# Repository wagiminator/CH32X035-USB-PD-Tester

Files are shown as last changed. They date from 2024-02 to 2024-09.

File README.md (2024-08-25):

# USB PD Tester
The USB PD Tester is a monitoring and triggering device designed for USB Power Delivery. It allows you to test a wide range of USB Type-C PD power supplies and their corresponding cables. This tool not only displays the capabilities of the power supply on an OLED but also enables you to select one of the available fixed or programmable voltages for output on the screw terminal. With this, it can also be used to power your projects with various selectable voltages and high currents, serving as a versatile variable power supply.

The USB PD Tester is built around the inexpensive (30 cents at the time of writing) and user-friendly CH32X035 RISC-V microcontroller, which comes with integrated USB 2.0, USB PD 2.0/3.0, and USB Type-C hardware support.

- Project video (Youtube): https://youtu.be/wqLiRnbcISo

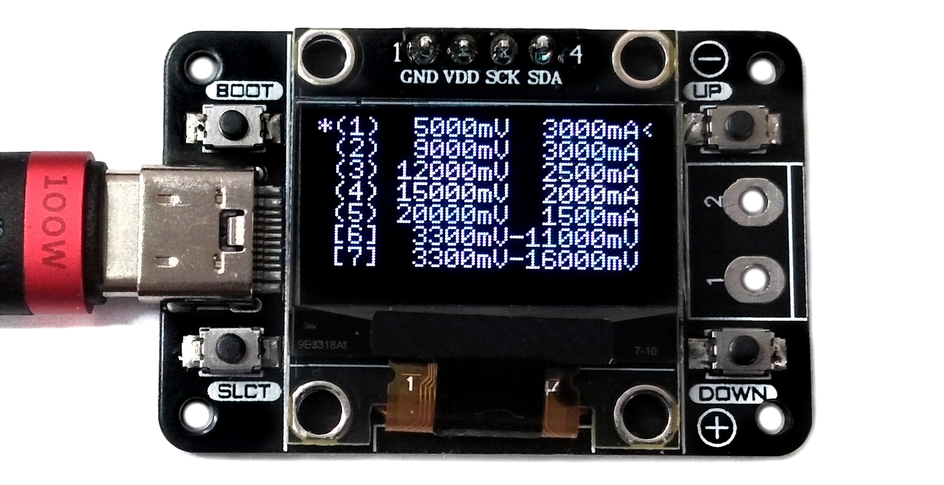
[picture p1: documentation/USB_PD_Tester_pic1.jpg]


# USB Power Delivery
USB Power Delivery (USB PD) is a protocol that extends the capabilities of standard USB connections, allowing for faster charging and power delivery between devices. USB PD operates through negotiation between the source and sink devices. They exchange information through PDOs, determining the optimal power level for charging or powering the sink device. PPS enhances flexibility by allowing dynamic adjustments, and CC1 and CC2 are the communication channels involved in the negotiation process:
- Source: The source is a device that provides power, such as a charger or power bank. It can negotiate with the connected device to determine the optimal power level. Here the USB PD power supply to be tested acts as the source.
- Sink: The sink is a device that consumes power, like a smartphone or laptop. It communicates with the source to negotiate the power it needs for charging or other operations. Here the USB PD Tester acts as the sink.
- PDO (Power Delivery Object): A PDO is a data structure exchanged between the source and sink during negotiation. It contains information about the available voltage and current levels. The devices negotiate and agree on a mutually supported PDO for power delivery.
- PPS (Programmable Power Supply): PPS is a feature in USB PD that allows dynamic adjustment of the voltage and current levels during operation. It enables more flexible power delivery based on the specific needs of the connected device.
- CC1 and CC2 (Configuration Channel 1 and 2): These are the communication channels used by USB Type-C connectors for negotiating power delivery. CC1 and CC2 lines carry information about the capabilities of the devices and facilitate negotiation.

# Hardware
## Schematic
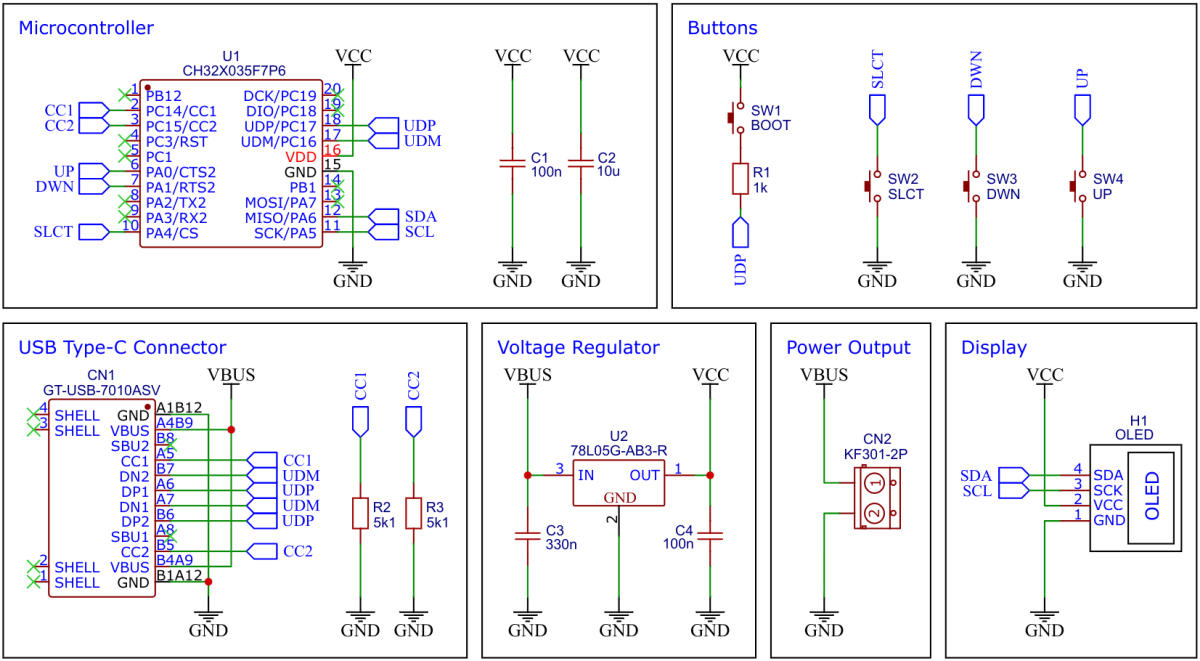
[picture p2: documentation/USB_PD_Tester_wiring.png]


## CH32X035 F7P6 32-bit RISC-V USB Microcontroller
CH32X035F7P6 is a low-cost microcontroller that utilizes the QingKe 32-bit RISC-V4C core, supporting the RV32IMAC instruction set along with self-extending instructions. This microcontroller comes with a built-in USB PHY, supporting USB2.0 full-speed device functions and a USB PD PHY with source and sink capabilities. It features a programmable protocol I/O controller (PIOC), an operational amplifier (OPA) with programmable gain (PGA), an analog comparator (CMP), a 12-bit analog-to-digital converter (ADC), an 11-channel touch-key controller, 3 groups of USART, I2C, SPI, multiple timers, and various other peripheral resources. The device can operate at clock frequencies of up to 48MHz and is compatible with a supply voltage range of 2.0V to 5.5V. The CH32X035F7P6 includes 48KB of flash, 20KB of SRAM, and an embedded USB bootloader.

## 78L05 Voltage Regulator
The 78L05 is a simple and inexpensive voltage regulator that can convert input voltages up to 30V to an output voltage of 5V with an output current of up to 100mA and a dropout voltage of 1.7V. The 78L05 supplies all elements of the circuit with up to 5V.

## SSD1306 OLED Display Module
A low-cost SSD1306 4-pin I2C 128x64 pixels 0.96-inch OLED module is used as the display device. Make sure to acquire one with the correct pinout!

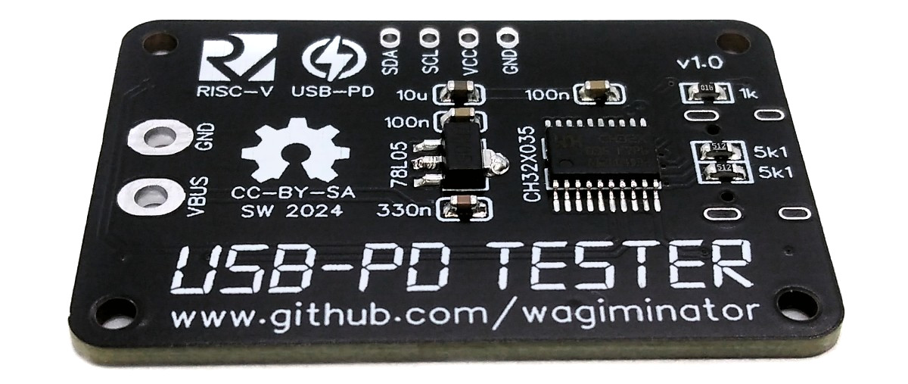
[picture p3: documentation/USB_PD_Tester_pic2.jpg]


# Software
## USB Bootloader
### Installing Drivers for the Bootloader
On Linux you do not need to install a driver. However, by default Linux will not expose enough permission to upload your code with the USB bootloader. In order to fix this, open a terminal and run the following commands:

```
echo 'SUBSYSTEM=="usb", ATTR{idVendor}=="4348", ATTR{idProduct}=="55e0", MODE="666"' | sudo tee /etc/udev/rules.d/99-ch55x.rules
echo 'SUBSYSTEM=="usb", ATTR{idVendor}=="1a86", ATTR{idProduct}=="55e0", MODE="666"' | sudo tee -a /etc/udev/rules.d/99-ch55x.rules
sudo udevadm
```

For Windows you can use the [Zadig](https://zadig.akeo.ie/) tool to install the correct driver. Here, click "Options" -> "List All Devices" and select the USB module. Then install the libusb-win32 driver. To do this, the board must be connected and the microcontroller must be in bootloader mode.

### Entering Bootloader Mode
The bootloader must be started manually for new uploads. To do this, the board must first be disconnected from the USB port. Now press the BOOT button and keep it pressed while reconnecting the board to the USB port of your PC. The chip now starts in bootloader mode, the BOOT button can be released and new firmware can be uploaded via USB within the next couple of seconds.

## Compiling and Uploading Firmware using the Makefile
### Linux
Install the toolchain (GCC compiler, Python3, and chprog):
```
sudo apt install build-essential libnewlib-dev gcc-riscv64-unknown-elf
sudo apt install python3 python3-pip
pip install chprog
```

Open a terminal and navigate to the folder with the *makefile*. Press the BOOT button and keep it pressed while connecting the board to the USB port of your PC. Run the following command to compile and upload:
```
make flash
```

### Other Operating Systems
Follow the instructions on [CNLohr's ch32v003fun page](https://github.com/cnlohr/ch32v003fun/wiki/Installation) to set up the toolchain on your respective operating system (for Windows, use WSL). Also, install [Python3](https://www.pythontutorial.net/getting-started/install-python/) and [chprog](https://pypi.org/project/chprog/). Compile and upload with "make flash". Note that I only have Debian-based Linux and have not tested it on other operating systems.

## Compiling and Uploading Firmware using PlatformIO
- Install [PlatformIO](https://platformio.org) and [platform-ch32v](https://github.com/Community-PIO-CH32V/platform-ch32v). Follow [these instructions](https://pio-ch32v.readthedocs.io/en/latest/installation.html) to do so. Linux/Mac users may also need to install [pyenv](https://realpython.com/intro-to-pyenv).
- Click on "Open Project" and select the firmware folder with the *platformio.ini* file.
- Press the BOOT button and keep it pressed while connecting the board to the USB port of your PC. Then click "Upload".

## Uploading pre-compiled Firmware Binary
WCH offers the free but closed-source software [WCHISPTool](https://www.wch.cn/downloads/WCHISPTool_Setup_exe.html) to upload firmware with Windows via the USB bootloader. Press the BOOT button and keep it pressed while connecting the board to the USB port of your PC. Release the BOOT button, open the *pd_tester.hex* file in the *bin* folder with WCHISPTool and upload it to the microcontroller.

If [Python3](https://www.pythontutorial.net/getting-started/install-python/) is installed, you can also use the platform-independent open-source command-line tool [chprog](https://pypi.org/project/chprog/) for uploading:
```
chprog bin/pd_tester.bin
```

# Building Instructions
1. Take the Gerber files (the *zip* file inside the *hardware* folder) and upload them to a PCB (printed circuit board) manufacturer of your choice (e.g., [JLCPCB](https://jlcpcb.com/)). They will use these files to create the circuit board for your device and send it to you.
2. Once you have the PCB, you can start soldering the components onto it. Use the BOM (bill of materials) and schematic as a guide to make sure everything is connected correctly. You can find the corresponding files in the *hardware* folder. Remove the plastic part from the pin header of the OLED, trim the pins, and solder the OLED module flush onto the PCB. Do not solder the screw terminal yet.
3. Print the casing with your 3D printer. You can find the corresponding *stl* files in the *3dprint* folder.
4. Insert the button extensions into the corresponding holes on the top part of the casing. Insert the circuit board and secure it with 4 self-tightening M2x5mm screws.
5. Now solder the screw terminal onto the circuit board.
6. Close the casing with the back panel.
7. Upload the firmware by following the instructions in the previous section (see above).

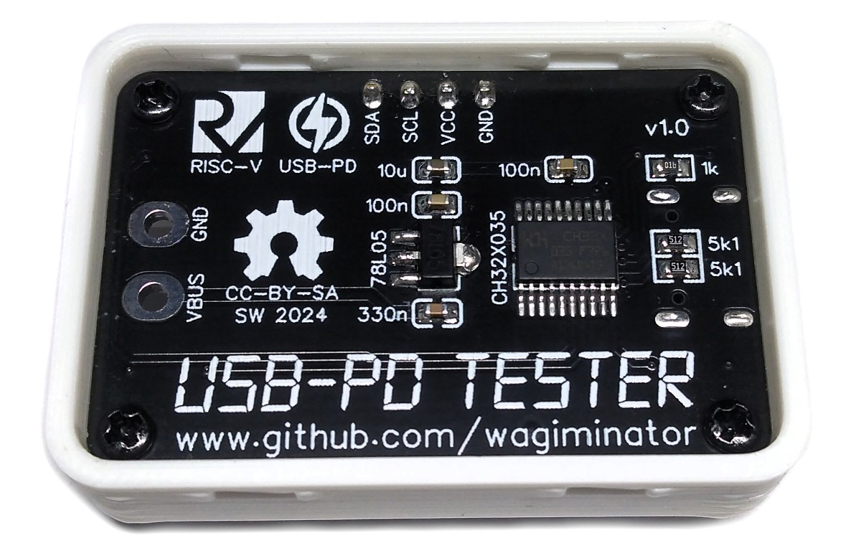
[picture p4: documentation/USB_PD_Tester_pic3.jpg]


# Operating Instructions
1. Connect the USB PD Tester to a USB Type-C PD power supply using a USB-C cable. The available PDOs and their corresponding capabilities are displayed on the OLED.
2. Utilize the UP and DOWN buttons to choose the desired PDO. A left-angle bracket on the right side serves as the selection indicator. Programmable PDOs, indicated by numbers within square brackets, allow precise adjustments of the output voltage in 20mV steps within the specified range.
3. Press the SLCT button to activate the chosen PDO. An asterisk on the left side of the PDO confirms the activation.
4. The selected voltage is now accessible on the screw terminal for further use.

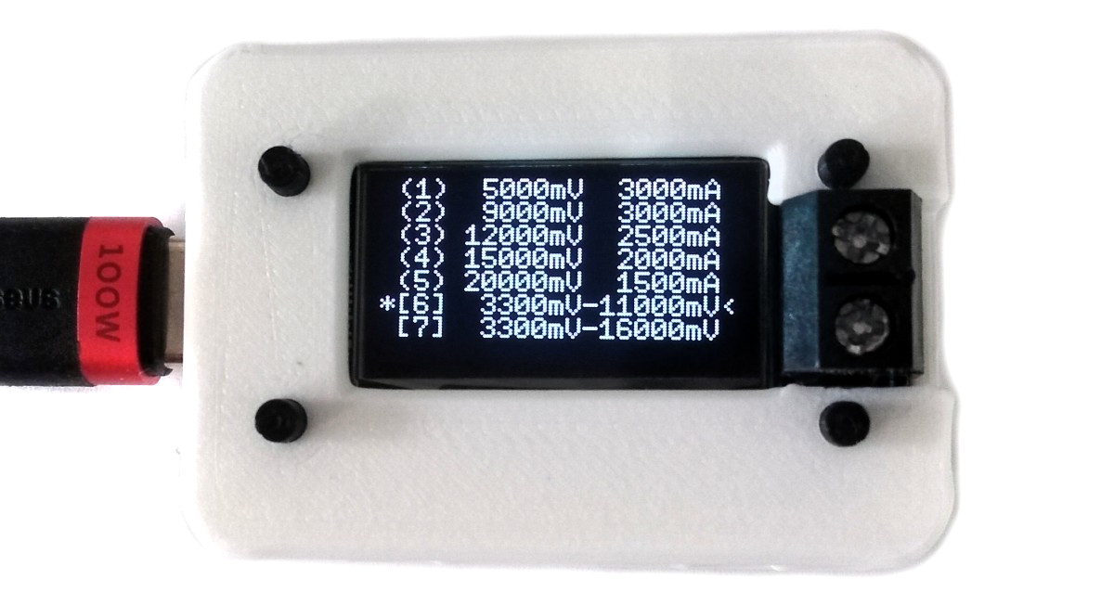
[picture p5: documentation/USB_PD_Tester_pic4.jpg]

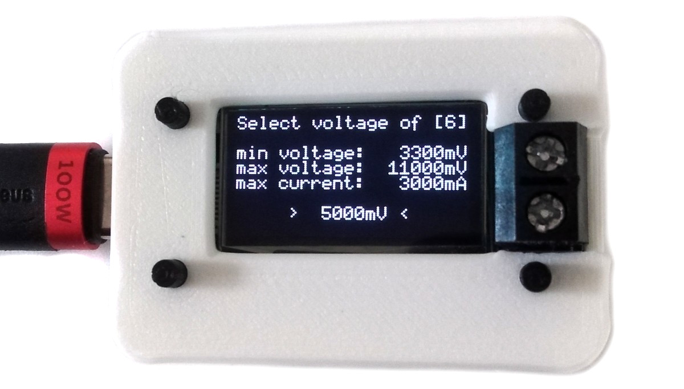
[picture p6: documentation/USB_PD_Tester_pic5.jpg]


# References, Links and Notes
- [EasyEDA Design Files](https://oshwlab.com/wagiminator)
- [MCU Templates](https://github.com/wagiminator/MCU-Templates)
- [MCU Flash Tools](https://github.com/wagiminator/MCU-Flash-Tools)
- [CH32X035 Datasheets](http://www.wch-ic.com/products/CH32X035.html)
- [SSD1306 Datasheet](https://cdn-shop.adafruit.com/datasheets/SSD1306.pdf)
- [78L05 Datasheet](https://datasheet.lcsc.com/lcsc/2209271730_HX-hengjiaxing-78L05_C5181466.pdf)
- [ATtiny814 USB PD Adapter](https://github.com/wagiminator/ATtiny814-USB-PD-Adapter)
- [ATtiny412 USB PD Inverter](https://github.com/wagiminator/ATtiny412-USB-PD-Inverter)
- [TI Primer on USB PD](https://www.ti.com/lit/wp/slyy109b/slyy109b.pdf)
- [CH32X035 F7P6 on Aliexpress](https://aliexpress.com/item/1005006199310724.html)
- [128x64 OLED on Aliexpress](https://aliexpress.com/wholesale?SearchText=128+64+0.96+oled)

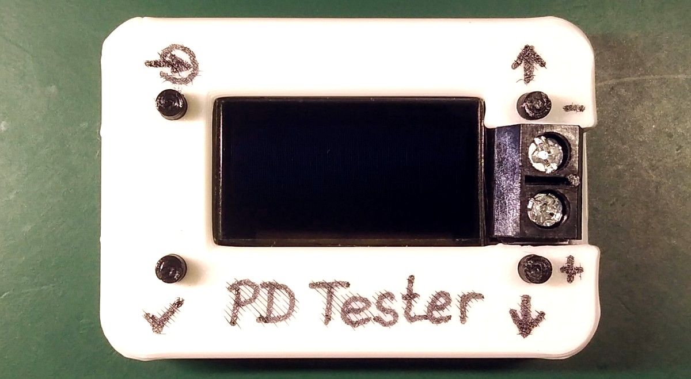
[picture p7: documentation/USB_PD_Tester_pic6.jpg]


# License


This work is licensed under Creative Commons Attribution-ShareAlike 3.0 Unported License. 
(http://creativecommons.org/licenses/by-sa/3.0/)

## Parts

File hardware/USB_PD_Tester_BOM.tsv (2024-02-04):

ID | Name | Designator | Footprint | Quantity | Manufacturer Part | Manufacturer | Supplier | Supplier Part
1 | 100n | C1,C4 | C_0603 | 2 | CC0603KRX7R9BB104 | YAGEO | LCSC | C14663
2 | 10u | C2 | C_0603 | 1 | CL10A106KP8NNNC | SAMSUNG | LCSC | C19702
3 | 330n | C3 | C_0603 | 1 | 0603B334K250NT | FH(风华) | LCSC | C1615
4 | GT-USB-7010ASV | CN1 | USB-C-7010ASV | 1 | GT-USB-7010ASV | G-Switch(品赞) | LCSC | C2988369
5 | KF301-2P | CN2 | KF301-2P | 1 | KF301-5.0-2P | Cixi Kefa Elec | LCSC | C474881
6 | OLED | H1 | I2C OLED 0.96 NEW | 1 | SSD1306 I2C OLED
7 | 1k | R1 | 0603 | 1 | 0603WAF1001T5E | UniOhm | LCSC | C21190
8 | 5k1 | R2,R3 | 0603 | 2 | 0603WAF5101T5E | UniOhm | LCSC | C23186
9 | BOOT | SW1 | SW-SMD_L4.0-W2.9-LS5.0 | 1 | YTS1T0092CBG00 | YIYUAN(怡远) | LCSC | C5221275
10 | SLCT | SW2 | SW-SMD_L4.0-W2.9-LS5.0 | 1 | YTS1T0092CBG00 | YIYUAN(怡远) | LCSC | C5221275
11 | DWN | SW3 | SW-SMD_L4.0-W2.9-LS5.0 | 1 | YTS1T0092CBG00 | YIYUAN(怡远) | LCSC | C5221275
12 | UP | SW4 | SW-SMD_L4.0-W2.9-LS5.0 | 1 | YTS1T0092CBG00 | YIYUAN(怡远) | LCSC | C5221275
13 | CH32X035F7P6 | U1 | TSSOP-20 | 1 | CH32X035F7P6 | WCH(南京沁恒) | LCSC
14 | 78L05G-AB3-R | U2 | SOT-89-3_BR | 1 | 78L05G-AB3-R | UTC(友顺) | LCSC | C71136

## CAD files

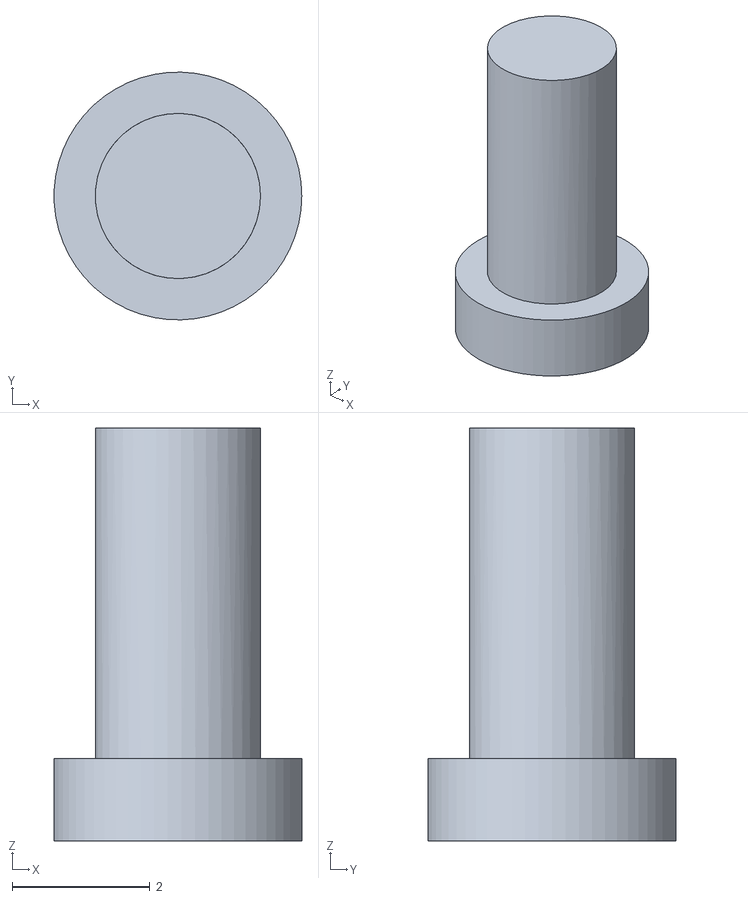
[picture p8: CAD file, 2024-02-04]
3dprint/USB_PD_Tester_case_button.stl
3.60 x 3.60 x 6.00

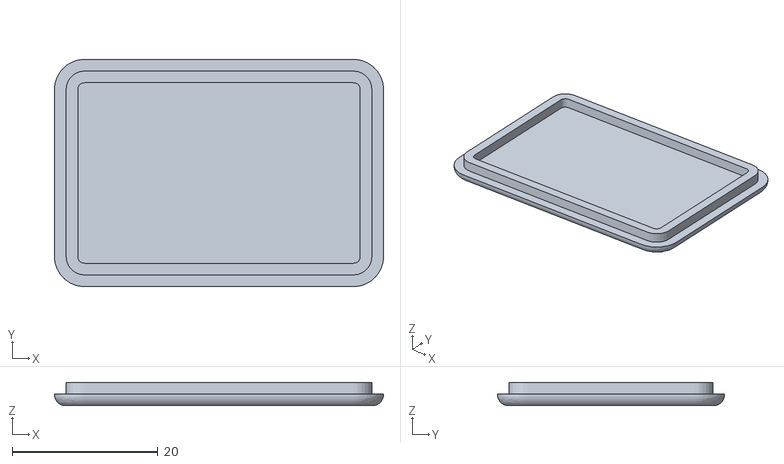
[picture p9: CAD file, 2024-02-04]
3dprint/USB_PD_Tester_case_bottom.stl
45.2 x 31.2 x 3.20

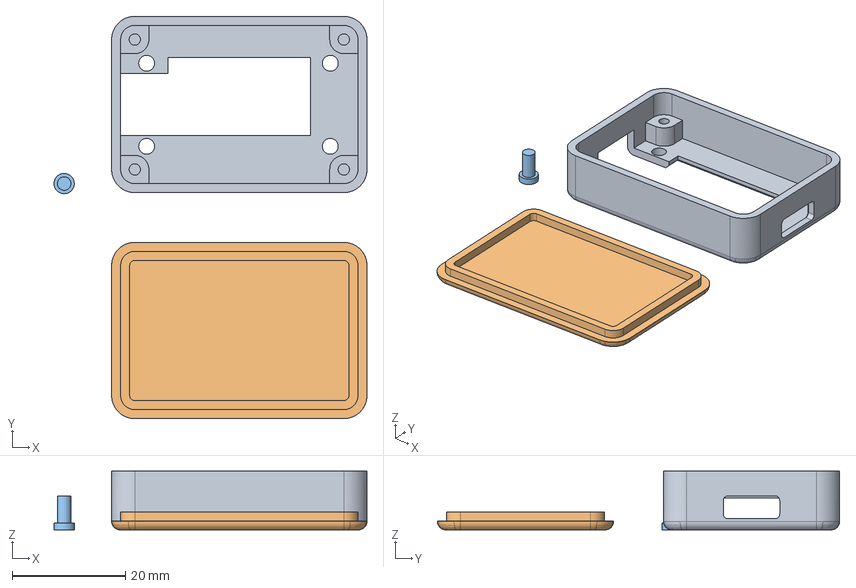
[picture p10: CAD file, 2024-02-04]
3dprint/USB_PD_Tester_case.FCStd
55.4 x 71.2 x 10.4 mm
case top
case bottom
case button

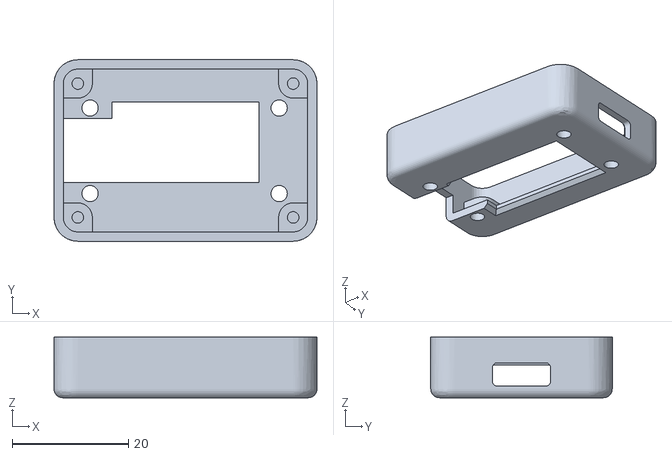
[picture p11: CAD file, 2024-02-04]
3dprint/USB_PD_Tester_case_top.stl
45.2 x 31.2 x 10.4

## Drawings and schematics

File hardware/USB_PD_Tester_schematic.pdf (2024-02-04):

## Microcontroller

# VCCUDP

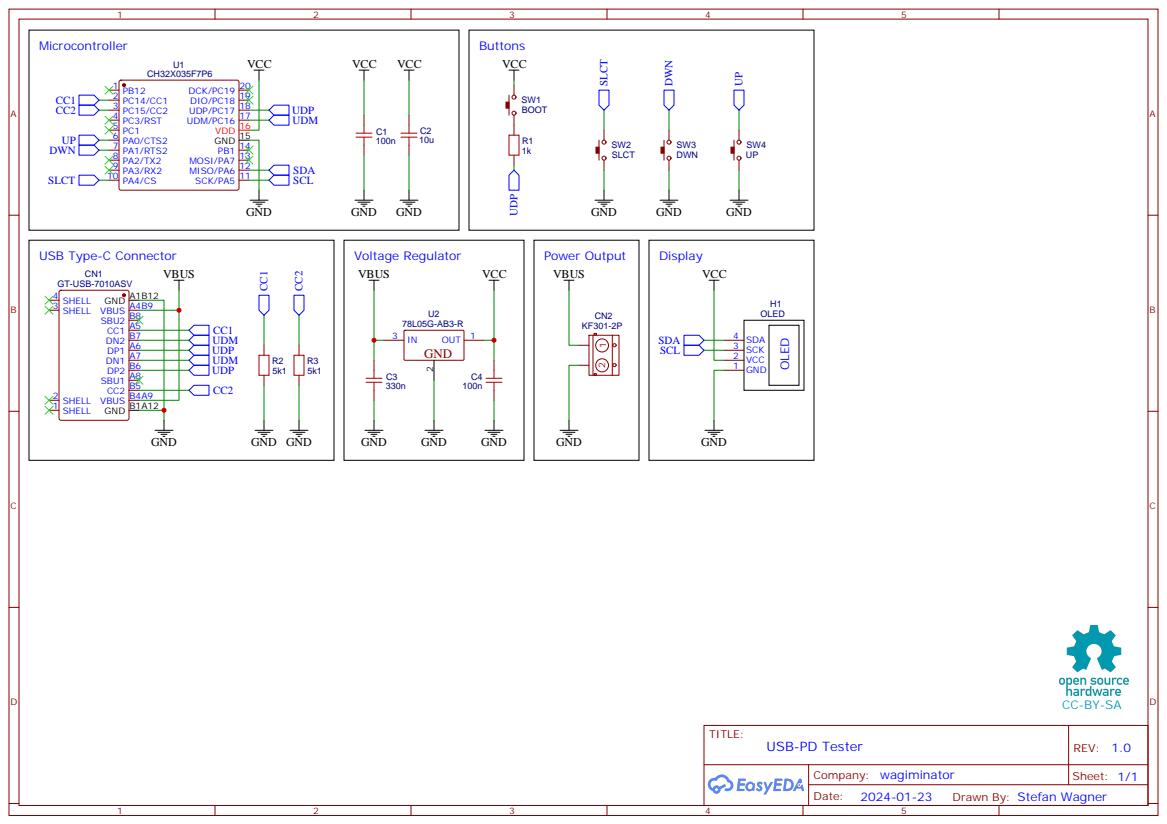
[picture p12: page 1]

Drawn By: Stefan Wagner

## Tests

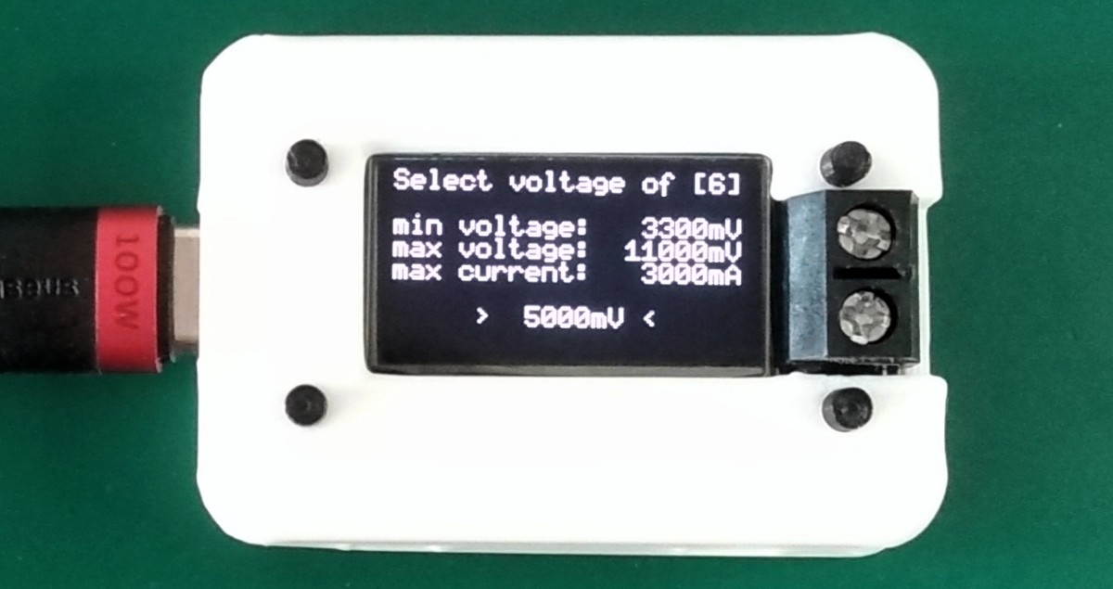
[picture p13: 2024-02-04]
documentation/USB_PD_Tester_pic8.jpg

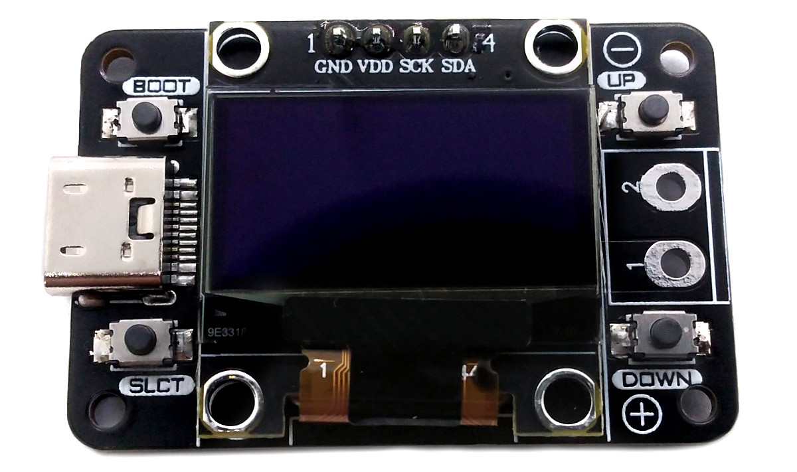
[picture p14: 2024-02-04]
documentation/USB_PD_Tester_pic9.jpg

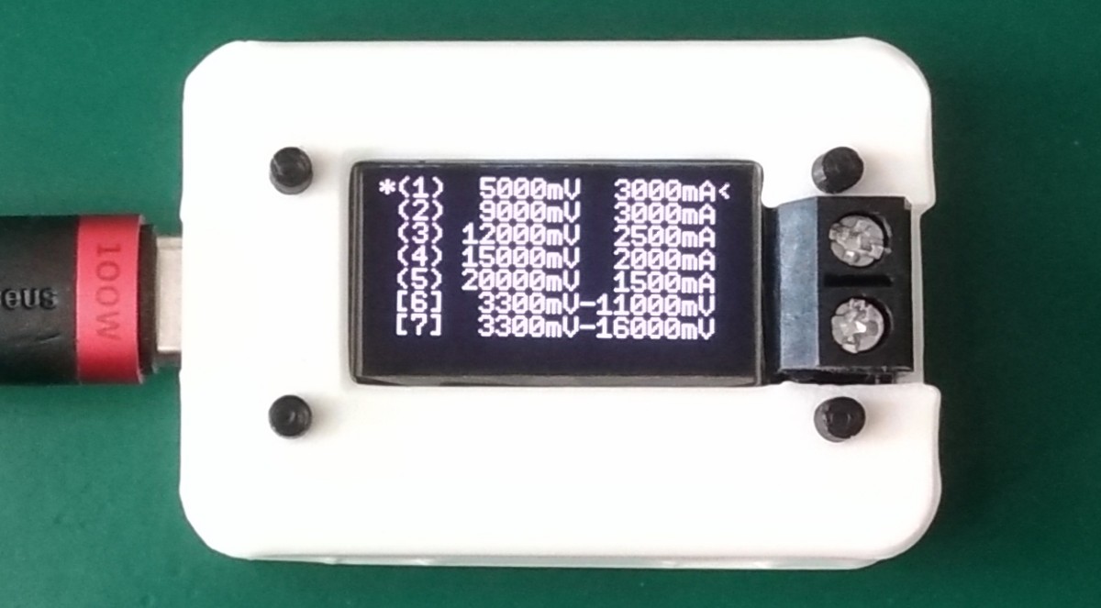
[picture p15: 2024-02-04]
documentation/USB_PD_Tester_pic7.jpg

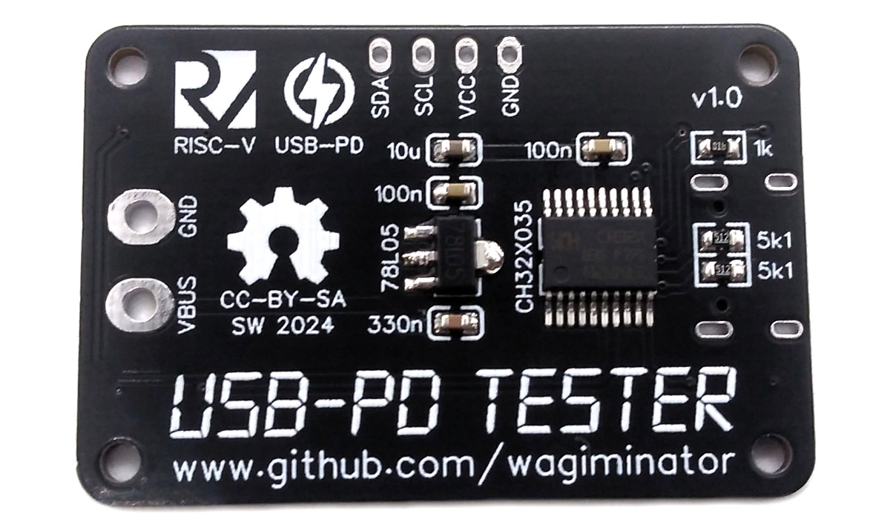
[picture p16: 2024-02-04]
documentation/USB_PD_Tester_pic10.jpg

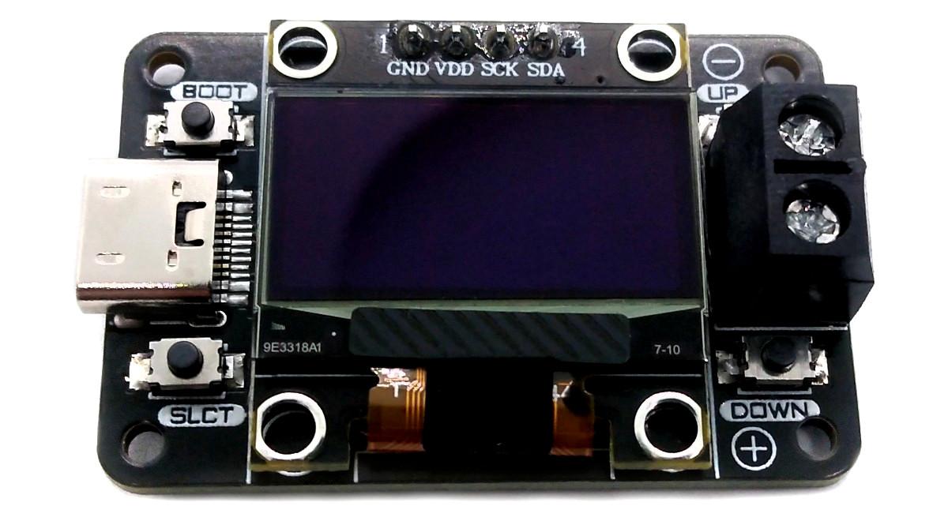
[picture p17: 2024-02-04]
documentation/USB_PD_Tester_pic11.jpg

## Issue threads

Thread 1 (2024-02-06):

PD 3.1 EPR support

drom, 2024-02-06:
Great project!
Do you plan supporting USB PD 3.1 EPR profiles {28, 36, 48}V ?
There are several 140W = 28V * 5A power bricks on the market right now to test.

wagiminator, 2024-02-06:
Thank you. I don't plan to do this at the moment. The hardware would have to be adapted so that it can tolerate the higher voltages (in particular, the cheap LDO should be replaced by a buck converter). When I have the appropriate power bricks at hand at some point, I'll definitely make a project out of them.

andelf, 2024-02-06:
I made something similar. :)

https://github.com/ch32-rs/ch32x0-hal/issues/1

wagiminator, 2024-02-06:
Coooooool! Now I know why I didn't get hardware-I2C to work....

andelf, 2024-02-06:
Yes. A sad story. It is documented in the datasheet, with only a single line of description.😤

wagiminator, 2024-02-06:
Ah, I just found the sentence in the datasheet. If I hadn't read it over, I could have saved myself frustrating hours with the logic analyzer.

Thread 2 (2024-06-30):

LCD supply voltage

martonmiklos, 2024-06-30:
Hi @wagiminator
Are you sure that the LCD could be powered from  5V?

martonmiklos, 2024-07-12:
Thanks, it looks like I managed to purchase a slightly different module.

Closed 2024-07-12.

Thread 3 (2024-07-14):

OLED warning

robots, 2024-07-14:
Hi,
I just build this device. Worked on first try! (nice job)

Sort of.

The OLED exists in multiple variants. I2C and SPI. While i bought the correct one 4pin, the pinout was VCC GND I2c i2c. Your pinout is GND VCC I2c I2c.

Probably worth mentioning for people interested in building.

(or maybe add 2 0R resistors on bottom that can be mounted  as || or = depending on source of oled)

wagiminator, 2024-07-22:
Thank you for the hint. I have not encountered OLEDs with a different pin configuration before. I am currently traveling and have a very busy schedule. Once I have a bit more time, I will add a corresponding note.

wagiminator, 2024-07-31:
I've added the info.

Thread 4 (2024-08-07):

Suggest changing U2 from an LDO to a zener diode

fs94007, 2024-08-07:
Suggest changing U2 from an LDO to a zener diode, as the operating current of U1 is less than 5mA, and the LDO seems a bit wasteful. After replacing U2 with a zener diode, the power supply cost decreases from ¥0.48 to ¥0.09.

An example of zener diode:
https://item.szlcsc.com/20275478.html?fromZone=l_c__%2522catalog%2522

wagiminator, 2024-08-07:
Hi and thanks for the hint. Of course, you can also solve this with a Zener diode, but I prefer to play it safe and stick with the LDO, even if it costs a few cents more.

Closed 2024-08-08.

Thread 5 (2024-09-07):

Restart in case of PPS

norbiv8, 2024-09-07:
Hi,
I rebulilt this project following your instructions which made the process smooth, thanks. I found that when I want to use PPS voltages the power supply and/or circuit restarts after some seconds after I set the desired voltage. With the fixed voltages (5V, 9V etc.) the issue is not appear. Tested with UGREEN 65W, 100W and SJÖSS (IKEA) 30W power supply too, all of them producing same issue. Lastly I tried with a cheap noname Aliexpress one which works without problem. The [CH32X035-USB-PD-Adapter](https://github.com/wagiminator/CH32X035-USB-PD-Adapter) behave very same. Have you tried with one of the power supplies above?

wagiminator, 2024-09-07:
Hi, thanks a lot for the information. I don’t have such a power supply myself; mine are all actually from Aliexpress. Could you please try if it works with a load connected to the output? Maybe the power supply shuts off if not enough current flows for a while (as an energy-saving measure). I know something like that, at least, from power banks.

norbiv8, 2024-09-07:
Hi Stefan,
thanks for good idea, it didn't come into my mind. During a test with 500mA load (it should be enough to keep alive the power supply) it producing same issue unfortunately. It looks like I have to dig into details to understand the root cause. Did you use the chip manufacturer example code for yor project?

wagiminator, 2024-09-07:
That's a shame, but I guess that would have been too easy.

I closely followed the manufacturer’s implementation, but of course, it’s quite possible that I may have overlooked something. What’s interesting is that the negotiation seems to work initially. Maybe it needs to be repeated regularly in this case. If you ever have a lot of time and feel like it, you could try testing the manufacturer’s implementation.

norbiv8, 2024-09-07:
I thought that it will be an easy Saturday afternoon project :D

Anyway, I hooked up logic analyzer to CC line, after negotiation or voltage set there is no regular communication on the line in case of the noname power supply. In case of UGREEN power supply the restart happens 13.8-13.9sec after last frame. I'm going to check the spec, it might necessary to initiate communication regularly as you wrote.
Just for curiosity I tried to decode the CC line, it is not perfect I mean not all frames decoded.
[increase_pps_to_5050mV_noname.txt](https://github.com/user-attachments/files/16919378/increase_pps_to_5050mV_noname.txt)
[increase_pps_to_5050mV_ugreen.txt](https://github.com/user-attachments/files/16919379/increase_pps_to_5050mV_ugreen.txt)
[negotiation_after_power_up_noname.txt](https://github.com/user-attachments/files/16919380/negotiation_after_power_up_noname.txt)
[negotiation_after_power_up_ugreen.txt](https://github.com/user-attachments/files/16919382/negotiation_after_power_up_ugreen.txt)
[restart_event_ugreen.txt](https://github.com/user-attachments/files/16919383/restart_event_ugreen.txt)

wagiminator, 2024-09-08:
What do you think, how many times I’ve looked forward to relaxed weekend projects? ;-)

Aha, that probably explains the problem. I guess I’ll have to take another look. Could you please try and see if the issue also occurs when you increase/decrease the requested voltage after about 10 seconds?

wagiminator, 2024-09-08:
I thought this was supposed to be a quiet Sunday morning :D

Try the updated version.

norbiv8, 2024-09-08:
I confirm it works with fiexd and PPS voltages too. Thanks!

wagiminator, 2024-09-08:
Great!

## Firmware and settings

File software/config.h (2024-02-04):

// ===================================================================================
// User configurations
// ===================================================================================

#pragma once

// Pin definitions
#define PIN_KEY_UP          PA0       // pin connected to UP button (active low)
#define PIN_KEY_DOWN        PA1       // pin connected to DOWN button (active low)
#define PIN_KEY_SLCT        PA4       // pin connected to SELECT button (active low)
#define PIN_SCL             PA5       // I2C SCL connected to OLED
#define PIN_SDA             PA6       // I2C SDA connected to OLED
#define PIN_LED             PB1       // pin connected to LED (active low)

// MCU supply voltage
#define USB_VDD             0         // 0: 3.3V, 1: 5V

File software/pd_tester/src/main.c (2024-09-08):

// ===================================================================================
// Project:   USB PD Tester for CH32X035
// Version:   v1.2
// Year:      2024
// Author:    Stefan Wagner
// Github:    https://github.com/wagiminator
// EasyEDA:   https://easyeda.com/wagiminator
// License:   http://creativecommons.org/licenses/by-sa/3.0/
// ===================================================================================
//
// Description:
// ------------
// The USB PD Tester allows users to retrieve and test the capabilities of a connected
// USB Power Delivery Adapter.
//
// References:
// -----------
// - WCH Nanjing Qinheng Microelectronics: http://wch.cn
//
// Compilation Instructions:
// -------------------------
// - Make sure GCC toolchain (gcc-riscv64-unknown-elf, newlib) and Python3 with chprog
//   are installed. In addition, Linux requires access rights to the USB bootloader.
// - Press the BOOT button on the MCU board and keep it pressed while connecting it
//   via USB to your PC.
// - Run 'make flash'.


// ===================================================================================
// Libraries, Definitions and Macros
// ===================================================================================
#include <config.h>             // user configurations
#include <ssd1306_txt.h>        // OLED text functions
#include <usbpd_sink.h>         // USB PD sink functions

// Global variables
uint8_t  select  = 1;           // selected PDO
uint8_t  active  = 1;           // active PDO
uint16_t voltage = 5000;        // selected voltage

// ===================================================================================
// Functions
// ===================================================================================

// Set selected PDO marker
void setSelect(uint8_t pdo) {
  OLED_cursor(120, select - 1); OLED_write(' ');
  if(pdo > PD_getPDONum()) select = 1;
  else if(pdo < 1)         select = PD_getPDONum();
  else                     select = pdo;
  OLED_cursor(120, select - 1); OLED_write('<');
}

// Set active PDO marker
void setActive(uint8_t pdo) {
  OLED_cursor( 0, active - 1); OLED_write(' ');
  active = pdo;
  OLED_cursor( 0, active - 1); OLED_write('*');
}

// Set selected voltage
void setVoltage(uint16_t v) {
  if     (v <= PD_getPDOMinVoltage(select)) voltage = PD_getPDOMinVoltage(select);
  else if(v >= PD_getPDOMaxVoltage(select)) voltage = PD_getPDOMaxVoltage(select);
  else                                      voltage = v;
  OLED_cursor(30, 6); OLED_printf(">%6dmV <", voltage);
}

// Print source capabilities
void printSourceCap(void) {
  uint8_t i;
  OLED_clear();
  for(i = 1; i <= PD_getPDONum(); i++) {
    if(i <= PD_getFixedNum())
      OLED_printf(" (%d)%6dmV %5dmA ", i, PD_getPDOVoltage(i), PD_getPDOMaxCurrent(i));
    else
      OLED_printf(" [%d]%6dmV-%5dmV ", i, PD_getPDOMinVoltage(i), PD_getPDOMaxVoltage(i));
  }
  setSelect(select);
  setActive(active);
}

// Print selected programmable power PDO infos
void printPPS(void) {
  OLED_clear();
  OLED_printf("Select voltage of [%d]\n", select);
  OLED_printf("min voltage:%7dmV", PD_getPDOMinVoltage(select));
  OLED_printf("max voltage:%7dmV", PD_getPDOMaxVoltage(select));
  OLED_printf("max current:%7dmA", PD_getPDOMaxCurrent(select));
  setVoltage(voltage);
}

// ===================================================================================
// Main Function
// ===================================================================================
int main(void) {
  // Variables
  uint8_t i;
  uint8_t keydelay;

  // Setup OLED and USB-PD
  OLED_init();
  OLED_clear();
  OLED_printf("Connecting...");
  if(!PD_connect()) {
    OLED_printf("FAILED");
    while(1);
  }

  // Print source capabilities
  printSourceCap();

  // Setup button pins
  PIN_input_PU(PIN_KEY_UP);
  PIN_input_PU(PIN_KEY_DOWN);
  PIN_input_PU(PIN_KEY_SLCT);
  
  // Loop
  while(1) {

    if(!PIN_read(PIN_KEY_UP)) {
      setSelect(select - 1);
      while(!PIN_read(PIN_KEY_UP));
    }

    if(!PIN_read(PIN_KEY_DOWN)) {
      setSelect(select + 1);
      while(!PIN_read(PIN_KEY_DOWN));
    }

    if(!PIN_read(PIN_KEY_SLCT)) {
      if(select <= PD_getFixedNum()) {
        if(PD_setPDO(select, PD_getPDOVoltage(select)))
          setActive(select);
      }
      else {
        printPPS();
        while(!PIN_read(PIN_KEY_SLCT));
        DLY_ms(10);
        while(PIN_read(PIN_KEY_SLCT)) {

          if(!PIN_read(PIN_KEY_UP)) {
            setVoltage(voltage + 20);
            i = keydelay;
            while((i--) && (!PIN_read(PIN_KEY_UP))) DLY_ms(10);
            keydelay = 2;
          }

          else if(!PIN_read(PIN_KEY_DOWN)) {
            setVoltage(voltage - 20);
            i = keydelay;
            while((i--) && (!PIN_read(PIN_KEY_DOWN))) DLY_ms(10);
            keydelay = 2;
          }

          else keydelay = 50;

          PD_negotiate();
        }

        if(PD_setPDO(select, voltage))
          active = select;
        printSourceCap();
      }
      while(!PIN_read(PIN_KEY_SLCT));
    }

    PD_negotiate();
    DLY_ms(10);
  }
}
